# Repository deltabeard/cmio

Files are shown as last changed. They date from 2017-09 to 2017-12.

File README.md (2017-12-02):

# cmio

**Note that this circuit is currently untested, as such I cannot guarantee that
it will function correctly.**

This is a custom Raspberry Pi Compute Module IO Board. Designed for low cost
production, and a minimal set of components.

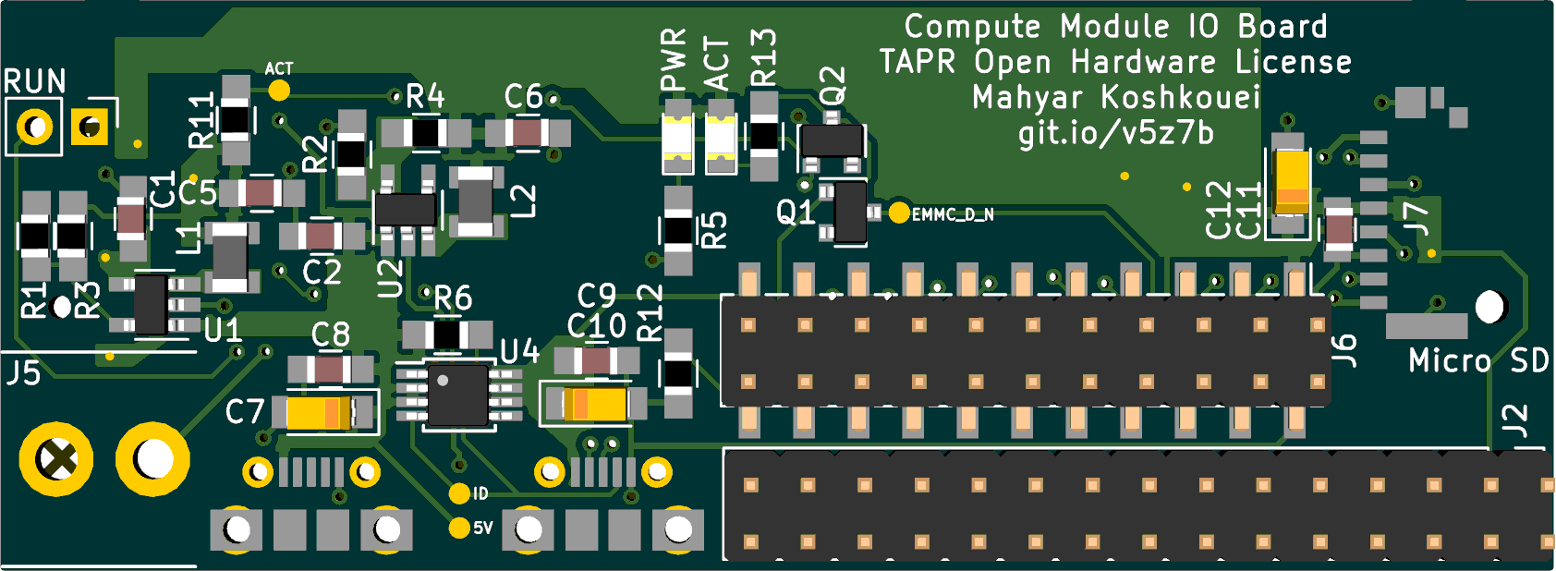
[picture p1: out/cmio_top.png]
Preview of the front of the PCB

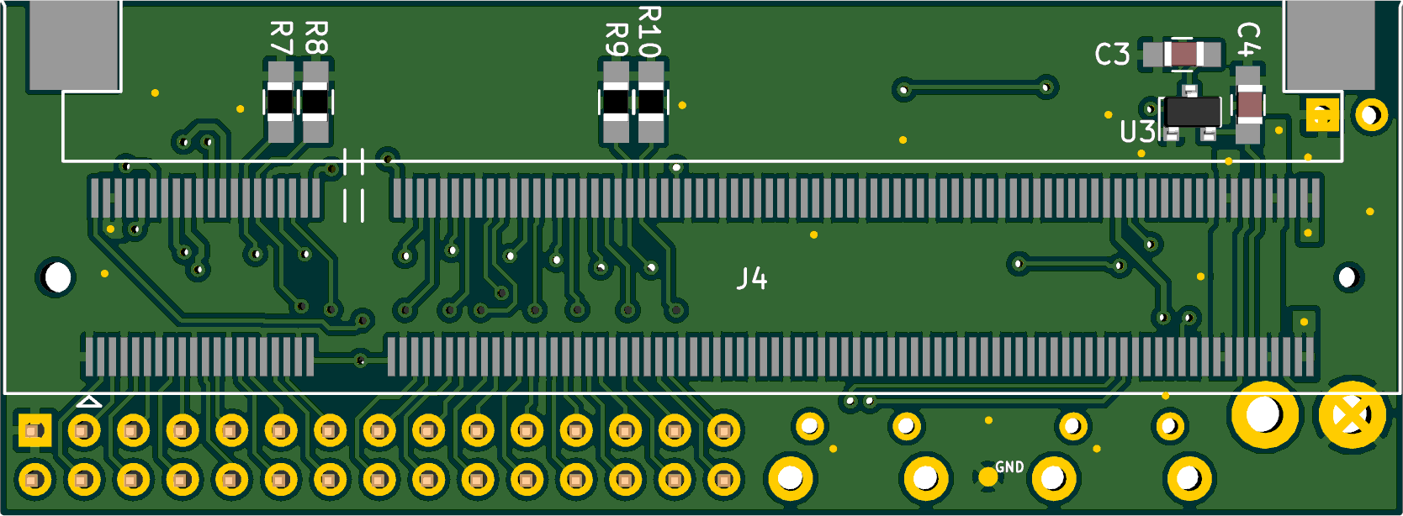
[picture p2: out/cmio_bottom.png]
Preview of the back of the PCB


Because low cost production was the main focus of the project, this Compute
Module IO board only has a subset of features in comparison to the official
version. However, whilst the official version costs £115, this design aims to
produce a Compute Module IO board that can be manufactured (PCB fabrication,
BOM, et al) under £30.

See BOM.md for the bill of materials, and for the costs required to manufacture
the latest release of this board.

This allows hobbyists an opportunity to introduce themselves to the Raspberry
Pi Compute Module without breaking the bank.

Features:
* Low cost design.
* Only low cost components required.
* Simple to solder with a heat gun.
* Micro SD card slot.
* Composite video output (No HDMI).
* Bank 0 and Bank 1 GPIO pins available.
* USB On-The-Go (OTG) support.
* Micro USB power input.
* Fully open source (KiCad files, etc. all available) under TAPR Open Hardware
  License.
* ~~A most excellent reset button!~~ [Removed in v0.5](https://github.com/deltabeard/cmio/commit/58f6f0d9b9edc8a3ccf51f042ef9ee13f27d9331)

Compatibility with the Raspberry Pi GPIO header was removed after v0.2 to
simplify the design and reduce cost of production.

\* Prices correct at the time of writing, are in Pound Sterling and include
VAT.

## Using this Repository

Note that only tagged releases should be used for manufacture (see the
[releases](https://github.com/deltabeard/cmio/releases) page). Other commits
should be deemed as work in progress.

Releases marked as "Pre-release" are not fully tested, and should not be used.
To this date, *no release version is fully working unfortunately*.

## Roadmap

Version v1.0 will denote a fully working board.

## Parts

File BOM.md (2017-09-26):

# Bill of materials for version 0.4

Items marked as a *Generic* manufacturer can typically be replaced with other components of the same value, size, etc.

Remember to perform your own research in to what component is best for you; there may be more cost effective components by the time you are reading this.

| Id | Designator | Quantity | Value | Notes | Supplier | Supplier Product Number | Manufacturer | Manufacturer Part Number | Datasheet URL | Cost Each | Cost Total | Cost (Per Pack) |
|----|---|---|---|---|---|---|---|---|---|---|---|---|
| 1 | J8 | 1 | Micro_SD_Card_TFP09_2_12B | SD Card Slot | Aliexpress | [32637089909](https://www.aliexpress.com/item/10Pcs-TransFlash-TF-Micro-Memory-SD-Card-Self-eject-Socket-Plug-Adapter/32637089909.html) | Centenary Materials | 104554/TFP09-2-12B | [URL](http://images.100y.com.tw/pdf_file/10-TFP09-2-12B.pdf)/[URL](http://us.100y.com.tw/viewproduct.asp?MNo=104554) | 0.055 | 0.055 | £0.55 |
| 2 | J7 | 1 | BANK1 | 2.54mm Pitch, SMD, 20-Pin | RS | [673-7339](http://uk.rs-online.com/web/p/pcb-headers/6737339/) | Generic | 95278-101-16LF | [URL](http://docs-europe.electrocomponents.com/webdocs/0d78/0900766b80d782a4.pdf) | 0.542 | 0.542 | £2.71 |
| 3 | C1,C2,C3,C4,C6,C7 | 6 | 4.7uF | Ceramic Cap, >6V, 0805 | RS | [698-3579](http://uk.rs-online.com/web/p/ceramic-multilayer-capacitors/6983579/) | Generic | 0805ZD475KAT2A | [URL](http://docs-europe.electrocomponents.com/webdocs/0def/0900766b80def1a5.pdf) | 0.027 | 0.162 | £0.27 |
| 4 | C5 | 1 | 10nF | Ceramic Cap, >6V, 0805 | RS | [264-4371](http://uk.rs-online.com/web/p/ceramic-multilayer-capacitors/2644371/) | Generic | C0805C103K5RACTU | [URL](http://docs-europe.electrocomponents.com/webdocs/1528/0900766b81528d88.pdf) | 0.019 | 0.019 | £0.48 |
| 5 | C8,C9,C11 | 3 | 0.1uF | Ceramic Cap, >6V, 0805 | RS | [264-4416](http://uk.rs-online.com/web/p/ceramic-multilayer-capacitors/2644416/) | Generic | C0805C104K5RACTU | [URL](http://docs-europe.electrocomponents.com/webdocs/1528/0900766b81528d8b.pdf) | 0.027 | 0.081 | £0.68 |
| 6 | L1,L2 | 2 | 2.2uH | Inductor, >500mA, 1008 | RS | [786-7112](http://uk.rs-online.com/web/p/multilayer-surface-mount-inductors/7867112/) | Generic | LQM2HPN2R2MG0L | [URL](http://docs-europe.electrocomponents.com/webdocs/1256/0900766b812561d9.pdf) | 0.2 | 0.4 | £2.00 |
| 7 | R1,R2,R6,R7,R8,R9 | 6 | 100k | Resistor, 0805 | RS | [223-0691](http://uk.rs-online.com/web/p/surface-mount-fixed-resistors/2230691/) | Generic | CRG0805F100K | [URL](http://docs-europe.electrocomponents.com/webdocs/13d0/0900766b813d043d.pdf) | 0.005 | 0.03 | £0.25 |
| 8 | R3 | 1 | 200k | Resistor, 0805 | RS | [832-6735](http://uk.rs-online.com/web/p/surface-mount-fixed-resistors/8326735/) | Generic | CRCW0805200KJNEA | [URL](http://docs-europe.electrocomponents.com/webdocs/13a4/0900766b813a4d36.pdf) | 0.027 | 0.027 | £0.27 |
| 9 | R4 | 1 | 450k | Resistor, 0805 | RS | [708-6925](http://uk.rs-online.com/web/p/surface-mount-fixed-resistors/7086925/) | Generic | ERA6AEB4533V | [URL](http://docs-europe.electrocomponents.com/webdocs/0eb1/0900766b80eb1d8c.pdf) | 0.042 | 0.042 | £0.21 |
| 10 | R5 | 1 | 10k | Resistor, 0805 | RS | [832-6723](http://uk.rs-online.com/web/p/surface-mount-fixed-resistors/8326723/) | Generic | CRCW080510K0JNEA | [URL](http://docs-europe.electrocomponents.com/webdocs/13a4/0900766b813a4d34.pdf) | 0.028 | 0.028 | £0.28 |
| 11 | SW1 | 1 | Reset | Tactile Push Button | Aliexpress | [32435561950](https://www.aliexpress.com/item/100-pcs-4-4-1-5mm-Tactile-Push-Button-Switch-Tact-Micro-Switch-4-Pin-SMD/32435561950.html) | Generic | - | - | 0.0113 | 0.0113 | £1.13 |
| 12 | U1,U2 | 2 | AP3417B | Buck, Adj, 1.2A, SOT-23, 5-Pin | RS | <font face="Liberation Serif">[828-7463](http://uk.rs-online.com/web/p/dc-dc-converters/8287463/)</font> | DiodesZetex | AP3417BK-ADJTRG1 | [URL](http://docs-europe.electrocomponents.com/webdocs/1332/0900766b81332189.pdf) | 0.099 | 0.198 | £2.48 |
| 13 | U3 | 1 | SP6203EM5-L-2-8/TR | LDO, 2.8V, 300mA, SOT-23, 5-Pin | RS | [686-5761](http://uk.rs-online.com/web/p/low-dropout-voltage-regulators/6865761/) | EXAR | SP6203EM5-L-2-8/TR | [URL](http://docs-europe.electrocomponents.com/webdocs/0d9e/0900766b80d9edfe.pdf) | 0.194 | 0.194 | £1.94 |
| 14 | U4 | 1 | AP2401 | USB Power Switch, Active Low, MSOP, 8-Pin | RS | [822-8830](http://uk.rs-online.com/web/p/usb-power-switches/8228830/) | DiodesZetex | AP2401MP-13 | [URL](http://docs-europe.electrocomponents.com/webdocs/1321/0900766b81321a76.pdf) | 0.081 | 0.081 | £2.03 |
| 15 | J3 | 1 | BANK0 | 2.54mm Pitch, Through hole, 30-Pin | RS | - | Generic | - | - | 0 | 0 | £0.00 |
| 16 | C10,C12 | 2 | 47uF | Tantalum Cap, >6V, 3216-18 | RS | [699-2860](http://uk.rs-online.com/web/p/tantalum-capacitors/6992860/) | AVX | TAJA476K006R | [URL](http://docs-europe.electrocomponents.com/webdocs/0df8/0900766b80df8b87.pdf) | 0.091 | 0.182 | £0.91 |
| 17 | J6 | 1 | TVOUT | Video Connector | Aliexpress | [32792221853](https://www.aliexpress.com/item/10PCS-LOT-AV-8-4-5-2x-Holes-2Pins-RCA-Sockets-90Degree-Audio-Video-Connecctors-Jacks/32792221853.html) | Generic | - | [URL](https://ae01.alicdn.com/kf/HTB101RLPFXXXXaMaXXXq6xXFXXXA/123434741/HTB101RLPFXXXXaMaXXXq6xXFXXXA.jpg) | 0.099 | 0.099 | £0.99 |
| 18 | J5 | 1 | CM3Lite | DDR2 DIMM Socket | RS | [719-8725](http://uk.rs-online.com/web/p/dimm-sockets/7198725/) | TE Connectivity | 1473149-4 | [URL](http://docs-europe.electrocomponents.com/webdocs/0f83/0900766b80f83e87.pdf) | 1.85 | 1.85 | £1.85 |
| 19 | J4 | 2 | USB_OTG/USB_POWER | USB Micro Socket | RS | [848-6764](http://uk.rs-online.com/web/p/micro-usb-connectors/8486764/) | Molex | 105017-0001 | [URL](http://docs-europe.electrocomponents.com/webdocs/1388/0900766b813885f7.pdf) | 0.356 | 0.712 | £1.78 |
| 20 | N/A | 1 | PCB Fabrication | Ordered with OSH Park | OSH Park | - | - | - | [URL](https://oshpark.com/) | 4.54667 | 4.54667 | £13.64 |

## Total

The total cost for the required quantity is **£9.26** without tax.

Because most of the items had to be purchased in bulk, the total cost is actually **£34.43** without tax.

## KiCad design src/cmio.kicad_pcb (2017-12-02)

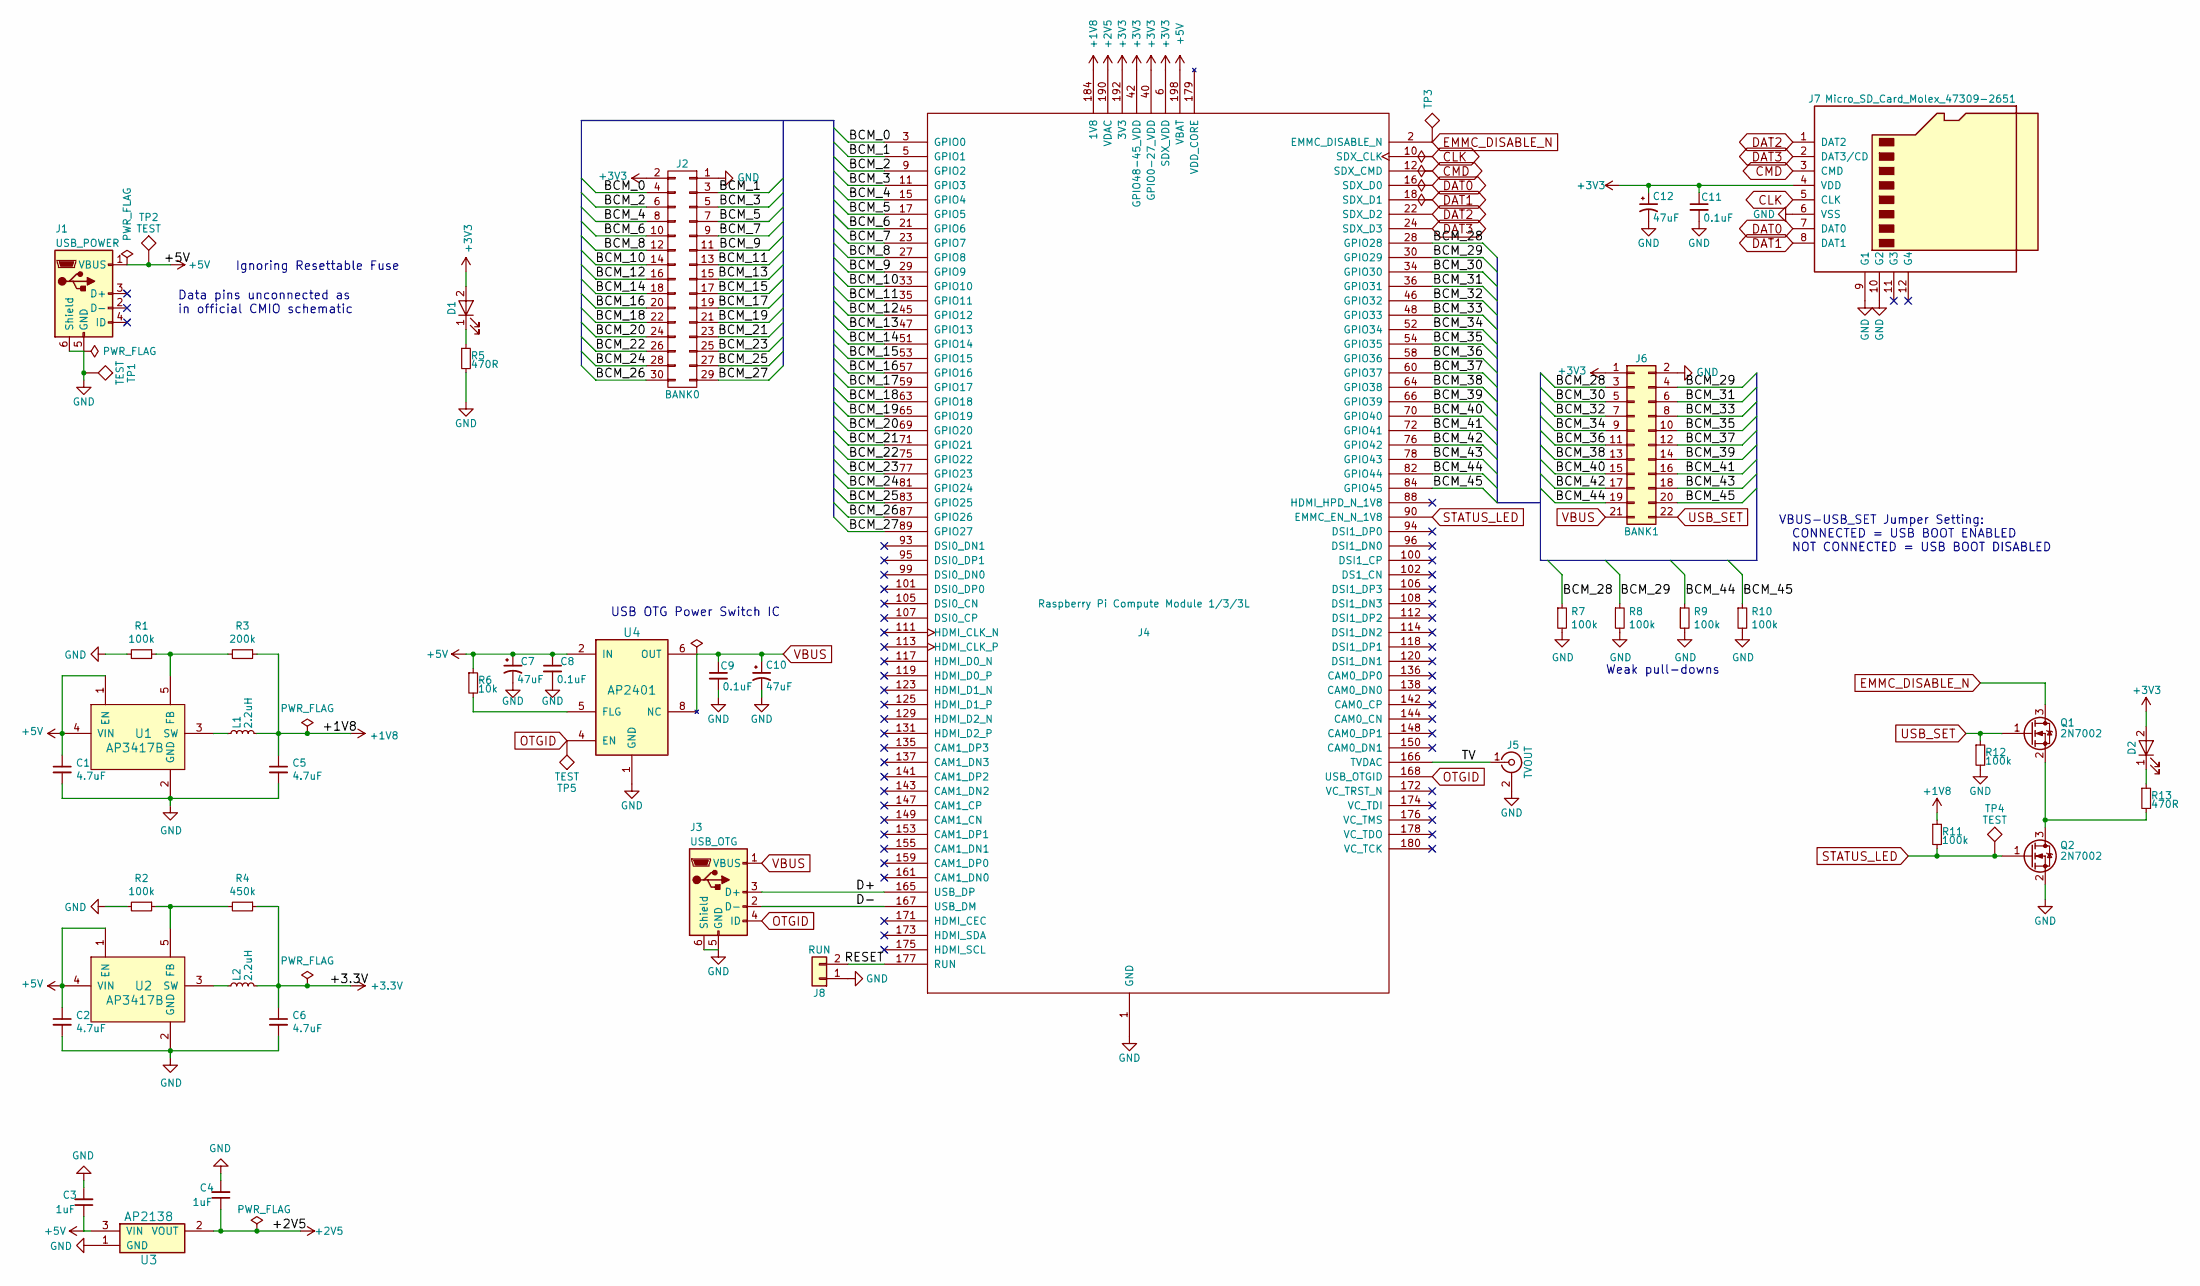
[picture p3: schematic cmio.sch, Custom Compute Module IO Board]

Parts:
C1, C2, C5, C6: 4.7uF; C_0805_HandSoldering
C3, C4: 1uF; C_0805_HandSoldering
C7, C10, C12: 47uF; CP_Tantalum_Case-A_EIA-3216-18_Reflow
C8, C9: 0.1uF; C_0805_HandSoldering
C11: 0.1uF; C_0805
D1: PWR LED; LED_0805
D2: STATUS LED; LED_0805
J1: USB_POWER; Molex_Right_Angle_SMT_TypeB_MicroUSB_105017_CircularOnly_an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
J2: BANK0; Pin_Header_Straight_2x15_Pitch2.54mm
J3: USB_OTG; Molex_Right_Angle_SMT_TypeB_MicroUSB_105017_CircularOnly_an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
J4: Raspberry Pi Compute Module 1/3/3L; CM3_Socket_SODIMM_DDR1-2_TE_1473149_4_NoHole_NoEndSilkS
J5: TVOUT; RCA_PHONO
J6: BANK1; Pin_Header_Straight_2x11_Pitch2.54mm_SMD
J7: Micro_SD_Card_Molex_47309-2651; Molex_Micro_SD_47309-2651
J8: RUN; Pin_Header_Straight_1x02_Pitch2.54mm
L1, L2: 2.2uH; Neosid_Inductor_SM-NE29_SMD1008
Q1, Q2: 2N7002; SOT-23
R1, R2, R7, R8, R9, R10, R11, R12: 100k; R_0805_HandSoldering
R3: 200k; R_0805_HandSoldering
R4: 450k; R_0805_HandSoldering
R5, R13: 470R; R_0805_HandSoldering
R6: 10k; R_0805_HandSoldering
TP1, TP2, TP3, TP4, TP5: TEST; Measurement_Point_Round-SMD-Pad_Small
U1, U2: AP3417B; SOT-23-5_HandSoldering
U3: AP2138; SOT-23
U4: AP2401; MSOP-8_3x3mm_Pitch0.65mm

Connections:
+1V8: C5.1, J4.183 (1V8), J4.184 (1V8), J4.185 (1V8), J4.186 (1V8), L1.2, R3.1, R11.1
+2V5: C4.1, J4.189 (VDAC), J4.190 (VDAC), U3.2 (VOUT)
+5V: C1.1, C2.1, C3.1, C7.1, C8.1, J1.1 (VBUS), J4.197 (VBAT), J4.198 (VBAT), J4.199 (VBAT), J4.200 (VBAT), R6.1, TP2.1, U1.1 (EN), U1.4 (VIN), U2.1 (EN), U2.4 (VIN), U3.3 (VIN), U4.2 (IN), U4.3 (IN)
/BCM_0: J2.4, J4.3 (GPIO0)
/BCM_1: J2.3, J4.5 (GPIO1)
/BCM_2: J2.6, J4.9 (GPIO2)
/BCM_3: J2.5, J4.11 (GPIO3)
/BCM_4: J2.8, J4.15 (GPIO4)
/BCM_5: J2.7, J4.17 (GPIO5)
/BCM_6: J2.10, J4.21 (GPIO6)
/BCM_7: J2.9, J4.23 (GPIO7)
/BCM_8: J2.12, J4.27 (GPIO8)
/BCM_9: J2.11, J4.29 (GPIO9)
/BCM_10: J2.14, J4.33 (GPIO10)
/BCM_11: J2.13, J4.35 (GPIO11)
/BCM_12: J2.16, J4.45 (GPIO12)
/BCM_13: J2.15, J4.47 (GPIO13)
/BCM_14: J2.18, J4.51 (GPIO14)
/BCM_15: J2.17, J4.53 (GPIO15)
/BCM_16: J2.20, J4.57 (GPIO16)
/BCM_17: J2.19, J4.59 (GPIO17)
/BCM_18: J2.22, J4.63 (GPIO18)
/BCM_19: J2.21, J4.65 (GPIO19)
/BCM_20: J2.24, J4.69 (GPIO20)
/BCM_21: J2.23, J4.71 (GPIO21)
/BCM_22: J2.26, J4.75 (GPIO22)
/BCM_23: J2.25, J4.77 (GPIO23)
/BCM_24: J2.28, J4.81 (GPIO24)
/BCM_25: J2.27, J4.83 (GPIO25)
/BCM_26: J2.30, J4.87 (GPIO26)
/BCM_27: J2.29, J4.89 (GPIO27)
/BCM_28: J4.28 (GPIO28), J6.3, R7.1
/BCM_29: J4.30 (GPIO29), J6.4, R8.1
/BCM_30: J4.34 (GPIO30), J6.5
/BCM_31: J4.36 (GPIO31), J6.6
/BCM_32: J4.46 (GPIO32), J6.7
/BCM_33: J4.48 (GPIO33), J6.8
/BCM_34: J4.52 (GPIO34), J6.9
/BCM_35: J4.54 (GPIO35), J6.10
/BCM_36: J4.58 (GPIO36), J6.11
/BCM_37: J4.60 (GPIO37), J6.12
/BCM_38: J4.64 (GPIO38), J6.13
/BCM_39: J4.66 (GPIO39), J6.14
/BCM_40: J4.70 (GPIO40), J6.15
/BCM_41: J4.72 (GPIO41), J6.16
/BCM_42: J4.76 (GPIO42), J6.17
/BCM_43: J4.78 (GPIO43), J6.18
/BCM_44: J4.82 (GPIO44), J6.19, R9.1
/BCM_45: J4.84 (GPIO45), J6.20, R10.1
/D+: J3.3 (D+), J4.165 (USB_DP)
/D-: J3.2 (D-), J4.167 (USB_DM)
/RESET: J4.177 (RUN), J8.2
/TV: J4.166 (TVDAC), J5.1 (In)
CLK: J4.10 (SDX_CLK), J7.5 (CLK)
CMD: J4.12 (SDX_CMD), J7.3 (CMD)
DAT0: J4.16 (SDX_D0), J7.7 (DAT0)
DAT1: J4.18 (SDX_D1), J7.8 (DAT1)
DAT2: J4.22 (SDX_D2), J7.1 (DAT2)
DAT3: J4.24 (SDX_D3), J7.2 (DAT3/CD)
EMMC_DISABLE_N: J4.2 (EMMC_DISABLE_N), Q1.3 (D), TP3.1
GND: C1.2, C2.2, C3.2, C4.2, C5.2, C6.2, C7.2, C8.2, C9.2, C10.2, C11.2, C12.2, J1.5 (GND), J1.6 (Shield), J2.1, J3.5 (GND), J3.6 (Shield), J4.1 (GND), J4.7 (GND), J4.8 (GND), J4.13 (GND), J4.14 (GND), J4.19 (GND), J4.20 (GND), J4.25 (GND), J4.26 (GND), J4.31 (GND), J4.32 (GND), J4.37 (GND), J4.38 (GND), J4.43 (GND), J4.44 (GND), J4.49 (GND), J4.50 (GND), J4.55 (GND), J4.56 (GND), J4.61 (GND), J4.62 (GND), J4.67 (GND), J4.68 (GND), J4.73 (GND), J4.74 (GND), J4.79 (GND), J4.80 (GND), J4.85 (GND), J4.86 (GND), J4.91 (GND), J4.92 (GND), J4.97 (GND), J4.98 (GND), J4.103 (GND), J4.104 (GND), J4.109 (GND), J4.110 (GND), J4.115 (GND), J4.116 (GND), J4.121 (GND), J4.122 (GND), J4.127 (GND), J4.133 (GND), J4.134 (GND), J4.139 (GND), J4.140 (GND), J4.145 (GND), J4.146 (GND), J4.151 (GND), J4.152 (GND), J4.157 (GND), J4.163 (GND), J4.164 (GND), J4.169 (GND), J4.170 (GND), J4.181 (GND), J4.182 (GND), J4.187 (GND), J4.188 (GND), J4.195 (GND), J4.196 (GND), J5.2 (Ext), J6.2, J7.6 (VSS), J7.9 (G1), J7.10 (G2), J8.1, Q2.2 (S), R1.2, R2.2, R5.2, R7.2, R8.2, R9.2, R10.2, R12.2, TP1.1, U1.2 (GND), U2.2 (GND), U3.1 (GND), U4.1 (GND)
unnamed: D1.1 (K), R5.1
unnamed: D2.1 (K), R13.1
unnamed: L1.1, U1.3 (SW)
unnamed: L2.1, U2.3 (SW)
unnamed: Q1.2 (S), Q2.3 (D), R13.2
unnamed: R1.1, R3.2, U1.5 (FB)
unnamed: R2.1, R4.2, U2.5 (FB)
unnamed: R6.2, U4.5 (FLG)
OTGID: J3.4 (ID), J4.168 (USB_OTGID), TP5.1, U4.4 (EN)
STATUS_LED: J4.90 (EMMC_EN_N_1V8), Q2.1 (G), R11.2, TP4.1
USB_SET: J6.22, Q1.1 (G), R12.1
VBUS: C9.1, C10.1, J3.1 (VBUS), J6.21, U4.6 (OUT), U4.7 (OUT), U4.8 (NC)

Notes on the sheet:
Weak pull-downs
Ignoring Resettable Fuse
Data pins unconnected as in official CMIO schematic
USB OTG Power Switch IC
VBUS-USB_SET Jumper Setting: CONNECTED = USB BOOT ENABLED NOT CONNECTED = USB BOOT DISABLED

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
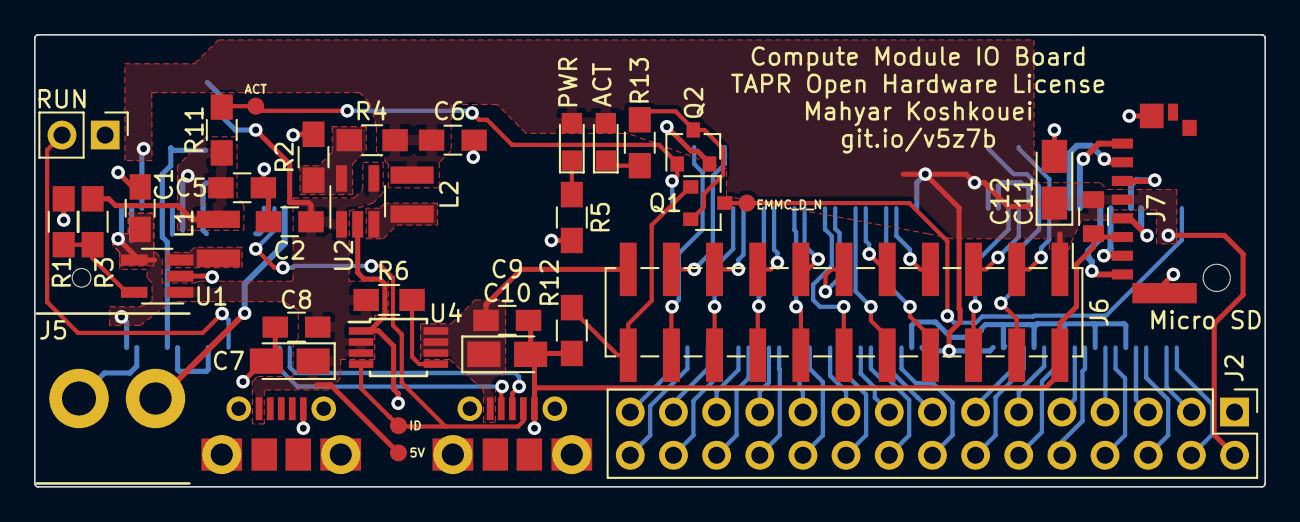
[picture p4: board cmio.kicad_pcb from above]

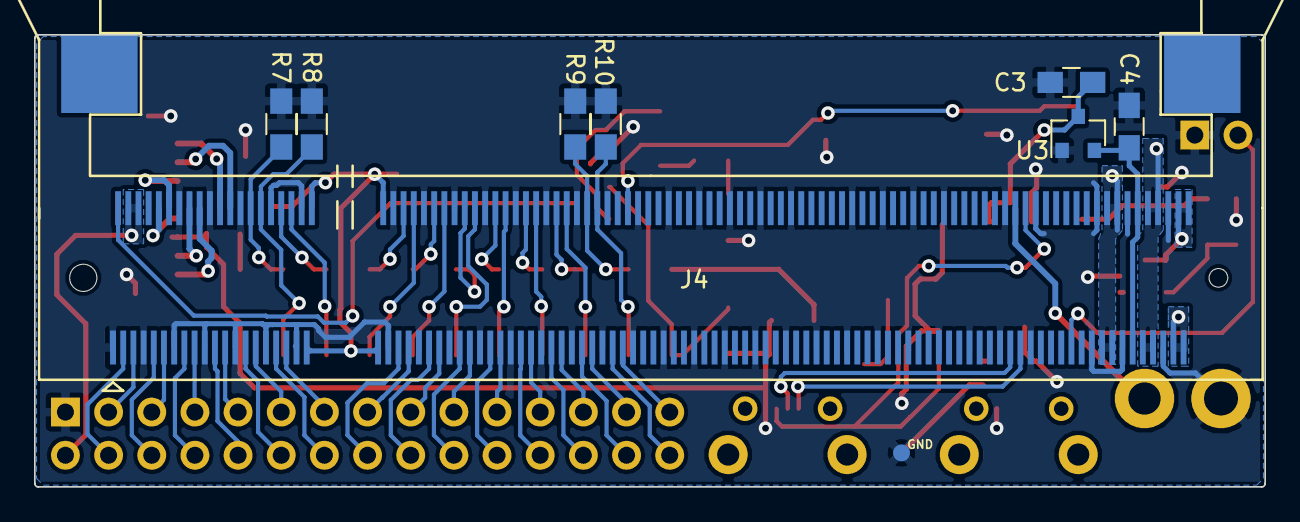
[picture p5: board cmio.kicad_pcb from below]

Board: 2 copper layers, 72.4 x 26.6 mm, 48 parts (9 on the bottom side), 74 nets.

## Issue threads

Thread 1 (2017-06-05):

Currently Untested

deltabeard, 2017-06-05:
This board is pending fabrication with a local supplier.

deltabeard, 2018-01-31:
Will remain open until a fully working board is produced.

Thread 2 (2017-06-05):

Poor decoupling

deltabeard, 2017-06-05:
Possible poor decoupling on 2V8 and 1V8 rails. This will be tested when first prototype is delivered.
Additionally, using 1uF capacitor instead of 4.7uF for SD Card.

deltabeard, 2017-06-05:
[Official compute module IO board](https://www.raspberrypi.org/documentation/hardware/computemodule/RPI-CMIO-V3_0-SCHEMATIC.pdf) uses 4.7uF, so sticking with that.

Closed 2017-09-10.

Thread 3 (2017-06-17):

Not enough clearance between 5V and 3.3V nets

deltabeard, 2017-06-17:

Closed 2017-09-20.

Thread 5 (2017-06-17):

Possibility of using a smaller inductor, with a lower current rating

deltabeard, 2017-06-17:

deltabeard, 2017-09-20:
Using a buck converter for 3.3V and 1.8V, each of which require at least 250mAh. Requirements for an inductor are reduced from >3.5A inductor to two >0.5mAh inductors. This is cheaper and smaller.

Closed 2017-09-20.

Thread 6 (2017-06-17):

EN_jumper footprint is incorrect

deltabeard, 2017-06-17:

deltabeard, 2017-06-19:
Removed the jumper completely, as the EN pin on the buck-boost converter has little use (I thought it was a "load disconnect" feature, but it's just a power saving feature).

Closed 2017-06-19.

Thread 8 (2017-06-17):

Add silkscreen label for Reset and TV output

deltabeard, 2017-06-17:

Closed 2017-06-19.

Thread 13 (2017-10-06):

Feature request: camera connectors

jholster, 2017-10-06:
Hi, thanks for such a cool project! I've been trying to create a similar project on circuits.io, but haven't gotten this far (I don't have any prior experience about pcb designing). My motivation is to have a CM3 IO board lightweight enough for model aircraft use, with stereo camera support for 3D FPV (first person flying). IMO, the dual camera support really makes Raspberry Pi an unique platform, but unfortunately the foundation hasn't exposed the needed pins in their 'consumer' boards (Zero/A/B).

I'm creating this issue just for general interest. I'll try to implement this by myself once I get familiar with Kicad.

deltabeard, 2017-10-06:
Hi! Thanks for your interest and kind words.

I've never looked in to camera support on the Raspberry Pi. Note that the two sets of camera pins are different. One is 4-lane and one is 2-lane. So you're going to have to make sure you use camera modules that are compatible with 4-lane and 2-lane respectively.

[Also note that the CSI ports on the Raspberry Pi are not openly documented.](https://www.raspberrypi.org/documentation/hardware/computemodule/RPI-CM-DATASHEET-V1_0.pdf) Only two camera modules are supported, and they probably only support one set of the CSI pins (the ones broken out on the Raspberry Pi). You may be able to find some light in this issue through the open source VC4 driver. Let me know how that goes.

I was very dissapointed to see that DSI has also poor documentation and nearly no support.

Let me know if you have any questions or want some help. :) Keep us updated!

jholster, 2017-10-07:
I've tested the dual camera setup with the official Compute Module Development Kit, so technically everything works fine, both software and hardware wise. AFAIK both cameras use only two data lines (cameras are interchangeable).

The only challenge with DIY board is that the CSI data lanes use differential pairs, requiring impedance matching and precice tolerances, but I've no idea how critical it is in practise (in hobbyist level).

deltabeard, 2017-10-08:
I had no idea!

KiCad has differential matching support, so that shouldn't be too much of an issue.

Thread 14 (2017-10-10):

RAM slot has incorrect footprint

deltabeard, 2017-10-10:
The two large copper pads are not in the right location. Care was not taken to verify the RAM slot footprint after part selection.

deltabeard, 2017-11-11:
Fixed in https://github.com/deltabeard/cmio/commit/d4816fb8157cfd9389859845206e4828535a8cb5

Closed 2017-11-11.

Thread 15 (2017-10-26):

Annular rings of Micro USB footprint too small

deltabeard, 2017-10-26:
This issue occurred because OSH Park does not support square holes. When the holes were changed to circular, the annular ring was not checked.

deltabeard, 2017-11-11:
Fixed in https://github.com/deltabeard/cmio/commit/99ae900dac507eecc18240359a092ee1d3c9fad7

Closed 2017-11-11.

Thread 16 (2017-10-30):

Use HDMI output instead of Composite (Maybe?)

deltabeard, 2017-10-30:
It'll be difficult to solder, but the RAM slot already is pretty difficult. This also removes the need for a 2.8V LDO.

deltabeard, 2017-11-11:
Using composite video is still easier to implement. Maybe this could be done in the future.

Closed 2017-11-11.

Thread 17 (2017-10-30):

No video output

deltabeard, 2017-10-30:
Built v0.4. Has no video output via the composite port.

Checking possibility that EMMC_DISABLE_N pin requires extra circuity to continue booting, although the Compute Module datasheet says this is only required under certain circumstances.

Have to check all pins on the RAM slot are correctly soldered.

deltabeard, 2017-11-02:
The Compute Module is detected by a connected USB host device when an SD card is not inserted on reset.

deltabeard, 2017-11-02:
Possible next steps:
* Connect the EMMC_DISABLE_N pin to an LED to check possible error codes.
* Activate serial connection and attempt to boot a Linux distro on it.

deltabeard, 2017-11-11:
It's difficult to get to the EMMC_DISABLE_N pin on the RAM slot, so a new version of the cmio will be manufactured.

deltabeard, 2017-11-16:
Nothing on the serial port is printed when using the bootcode.bin file with extra debugging enabled.

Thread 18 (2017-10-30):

Add power and usage LEDs

deltabeard, 2017-10-30:
These would have been helpful for debugging. I currently have to use a multimeter to check if the unit is switched on. I could however just use the 3.3V pin on the GPIO slot for power LED.

deltabeard, 2017-11-11:
Added in https://github.com/deltabeard/cmio/commit/6eba2f18fcc776e17d381fbbbd63cd1da77aba90

Closed 2017-11-11.

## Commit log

2017-05-24 Add Computer Module 3 Lite
    [cmio.kicad_pcb, cmio.sch]
2017-05-25 Add LDO for 2.8V and 1.8V
    [cmio.kicad_pcb, cmio.sch]
2017-05-26 Add Micro SD Card Footprint and 20-TQFP
    [cmio.kicad_pcb, cmio.sch]
2017-05-27 Before removing RPi GPIO Compat
    [cmio.kicad_pcb, cmio.sch]
2017-05-27 Nearly finished routing
    Remember to remove redundant GND tracks
    [cmio.kicad_pcb, cmio.sch]
2017-05-28 Final Checks
    [cmio.kicad_pcb, cmio.sch]
2017-06-05 Many changes
    Added pull downs to the four GPIO pins that do not have a pull down or
    pull up integrated.
    Using surface mount pin sockets to reduce PCB space.
    Using copper fills for some power tracks.
    Using thicker tracks for power.
    Added decoupling capacitor close to SD card.
    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
    [cmio.kicad_pcb, cmio.sch]
2017-06-19 Minor changes that I can't remember
    [cmio.kicad_pcb]
2017-06-19 Many Changes
    * Add voltage test points. Fixes #10.
    * Repositioned components.
    * Removed some jumpers.
    * Added clearer silkscreen for Reset and TV output. Fixes #8.
    * Fixed Micro USB footprints. Fixes #4.
    [cmio.kicad_pcb, cmio.sch]
2017-06-22 Finish routing
    Additionally, added micro USB socket without holes.
    [cmio.kicad_pcb]
2017-06-24 Cleanup and new release
    [cmio.kicad_pcb]
2017-09-02 Some changes to old design
    [cmio.kicad_pcb, cmio.sch]
2017-09-03 Complete Redesign
    - Fixed the net name of OTGID.
    - Fixed USB OTG power switch.
    - Added more decoupling capacitors.
    - Connected VBAT directly to 5V.
    - Changed Buck-Boost converter to Buck converter with reduced output
    current.
    [cmio.sch]
2017-09-03 Fix footprint tags
2017-09-07 Finish PCB Routing
    [cmio.kicad_pcb, cmio.sch]
2017-09-10 Simplify CM3 Module Part
    Additionally removed some unnecessary decoupling capacitors.
    Additionally changes the pin allocations on GPIO Bank 1 to optimise
    track length.
    Additionally added PWR_FLAG to fix some ERC errors.
    [cmio.kicad_pcb, cmio.sch]
2017-09-10 Improve CM3 Footprint
    Additionally removed electrolytic capacitors.
    Re-annotated components and cleared board.
    [cmio.kicad_pcb, cmio.sch]
2017-09-10 Add Heatsink Footprint
    It's cheap, large, and will most likely work well with the heat output
    of the Compute Module 3.
2017-09-17 Add USB and Heatsink footprints
2017-09-17 Replaced ICs
    Using buck converters with simpler design requirements and lower cost.
    Using an LDO for VDAC due to lower noise and low current requirements.
    [cmio.kicad_pcb, cmio.sch]
2017-09-17 Add associations
    [cmio.sch]
2017-09-17 Some work on PCB
    [cmio.kicad_pcb]
2017-09-17 Remove compatibility with RPi for simpler design
    [cmio.sch]
2017-09-20 Complete routing
    [cmio.kicad_pcb, cmio.sch]
2017-09-20 Add Board info to Silk Screen
    [cmio.kicad_pcb]
2017-09-21 Add GND VIAs
    [cmio.kicad_pcb]
2017-09-22 Add test points
    [cmio.kicad_pcb, cmio.sch]
2017-09-22 Change Micro USB footprint with circular pads only
    For support with OSH Park.
    [cmio.kicad_pcb, cmio.sch]
2017-09-25 Change license to TAPR Open Hardware License
    [cmio.kicad_pcb, cmio.sch]
2017-09-26 Use little k for resistor values
    [cmio.sch]
2017-09-26 Add message to see BOM.md in README
2017-09-26 Add BOM source spreadsheet
    [bom.ods]
2017-11-10 Fixed RAM slot footprint
    Fixed an issue whereby the two large pads where not the right size or in
    the right place.
2017-11-10 Fix annular ring of USB footprint
2017-11-11 Add more footprints
2017-11-11 Major Changes
    - Add USB Boot setting
    - Add Status and Power LEDs
    - Added a second Micro SD slot with a different footprint to allow users
    more variety. They cannot be used at the same time.
    - Use 2.5V for Video DAC, as used in the official CMIO board.
    - Add test points.
    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
    [cmio.sch]
2017-11-11 Minor changes
    These are minor changes that missed previous commits as I forgot to
    save.
    [cmio.sch]
2017-11-12 Fix DRC issues
    Additionally added repository URL to title block.
    [cmio.kicad_pcb, cmio.sch]
2017-11-13 Complete Placement
    [cmio.kicad_pcb, cmio.sch]
2017-11-20 Finish routing
    [cmio.kicad_pcb, cmio.sch]
2017-11-20 Change to IO board
    [cmio.kicad_pcb]
2017-12-01 Add cap and minor changes
    Added an extra decoupling capacitor to the SD socket.
    Replaced the RUN button with an unpopulated two pin header as seen on
    the Raspberry Pi. I can't imagine RUN being used often enough to warrant
    a button.
    Only use one Micro SD socket footprint.
    [cmio.kicad_pcb, cmio.sch]
2017-12-02 Increase size of 3V3 plane
    [cmio.kicad_pcb]

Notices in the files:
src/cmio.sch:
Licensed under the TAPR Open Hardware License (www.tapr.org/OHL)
